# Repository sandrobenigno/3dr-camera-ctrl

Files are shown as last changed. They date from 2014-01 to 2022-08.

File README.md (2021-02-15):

3dr-camera-ctrl
===============

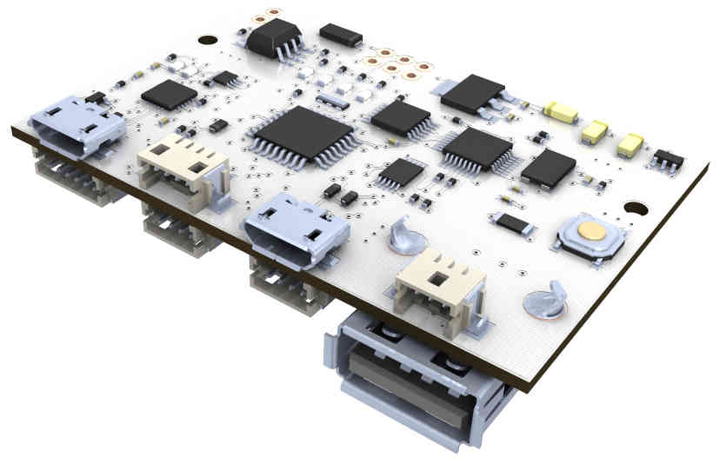
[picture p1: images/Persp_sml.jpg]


3DR Camera Control Board with USB Host

ArduCam PTP CHDK - Arduino based Remote CHDK Camera Control.
This firmware is part of the ArduCAM OSD Project: an open source Arduino based OSD and Camera Control.

<pre>
Author(s): Sandro Benigno
           Legacy PTP commands from Canon's PS-ReCSDK 1.1.0e
           Custom extended PTP commands from CHDK's PTP implementation
           USB host and PTP library from Oleg Mazurov - circuitsathome.com

Note: The PTP library used here was modified by the author.
      There are special characteristics needed to cover the scripting approach.
      The CHDK PTP Transaction has a wider RX buffer (reflected on the dataSize flag).
</pre>

This program is free software; you can redistribute it and/or
modify it under the terms of the GNU General Public License
as published by the Free Software Foundation; either version 2+
of the License, or (at your option) any later version.

This program is distributed in the hope that it will be useful,
but WITHOUT ANY WARRANTY; without even the implied warranty of
MERCHANTABILITY or FITNESS FOR A PARTICULAR PURPOSE.  See the
GNU General Public License for more details.

You should have received a copy of the GNU General Public License
along with this program. If not, see <http://www.gnu.org/licenses/>.

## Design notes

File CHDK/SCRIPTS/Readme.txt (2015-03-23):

GeoShooting base-code for Camera Control over CHDK PTP
This code is part of ArduCAMPTP_CHDK's implementetion for 3DRobotics.

This program is free software; you can redistribute it and/or
modify it under the terms of the GNU General Public License
as published by the Free Software Foundation; either version 2+
of the License, or (at your option) any later version.

This program is distributed in the hope that it will be useful,
but WITHOUT ANY WARRANTY; without even the implied warranty of
MERCHANTABILITY or FITNESS FOR A PARTICULAR PURPOSE.  See the
GNU General Public License for more details.

You should have received a copy of the GNU General Public License
along with this program. If not, see <http://www.gnu.org/licenses/>.

Project page: https://github.com/sandrobenigno/3dr-camera-ctrl

This script receives arguments in a packet of PTP Transaction:

lat   = params[1] <- Latitude.     (E.g. 47.266273)
lon   = params[2] <- Longitude.    (E.g. 11.302096)
alt   = params[3] <- Altitude ASL. (E.g. 1083.22)
pitch = params[4] <- Pitch         (-180 to 180)
row   = params[5] <- Roll          (-180 to 180)
yaw   = params[6] <- Heading       (0.00 <= X < 360.00)

It takes a picture and create/update a file "geostore.csv" on the folder session the taken picture.

Each line of this file looks like this:
IMG_0673.JPG,47.266273,11.302096,1083.22,7,-35,210.00

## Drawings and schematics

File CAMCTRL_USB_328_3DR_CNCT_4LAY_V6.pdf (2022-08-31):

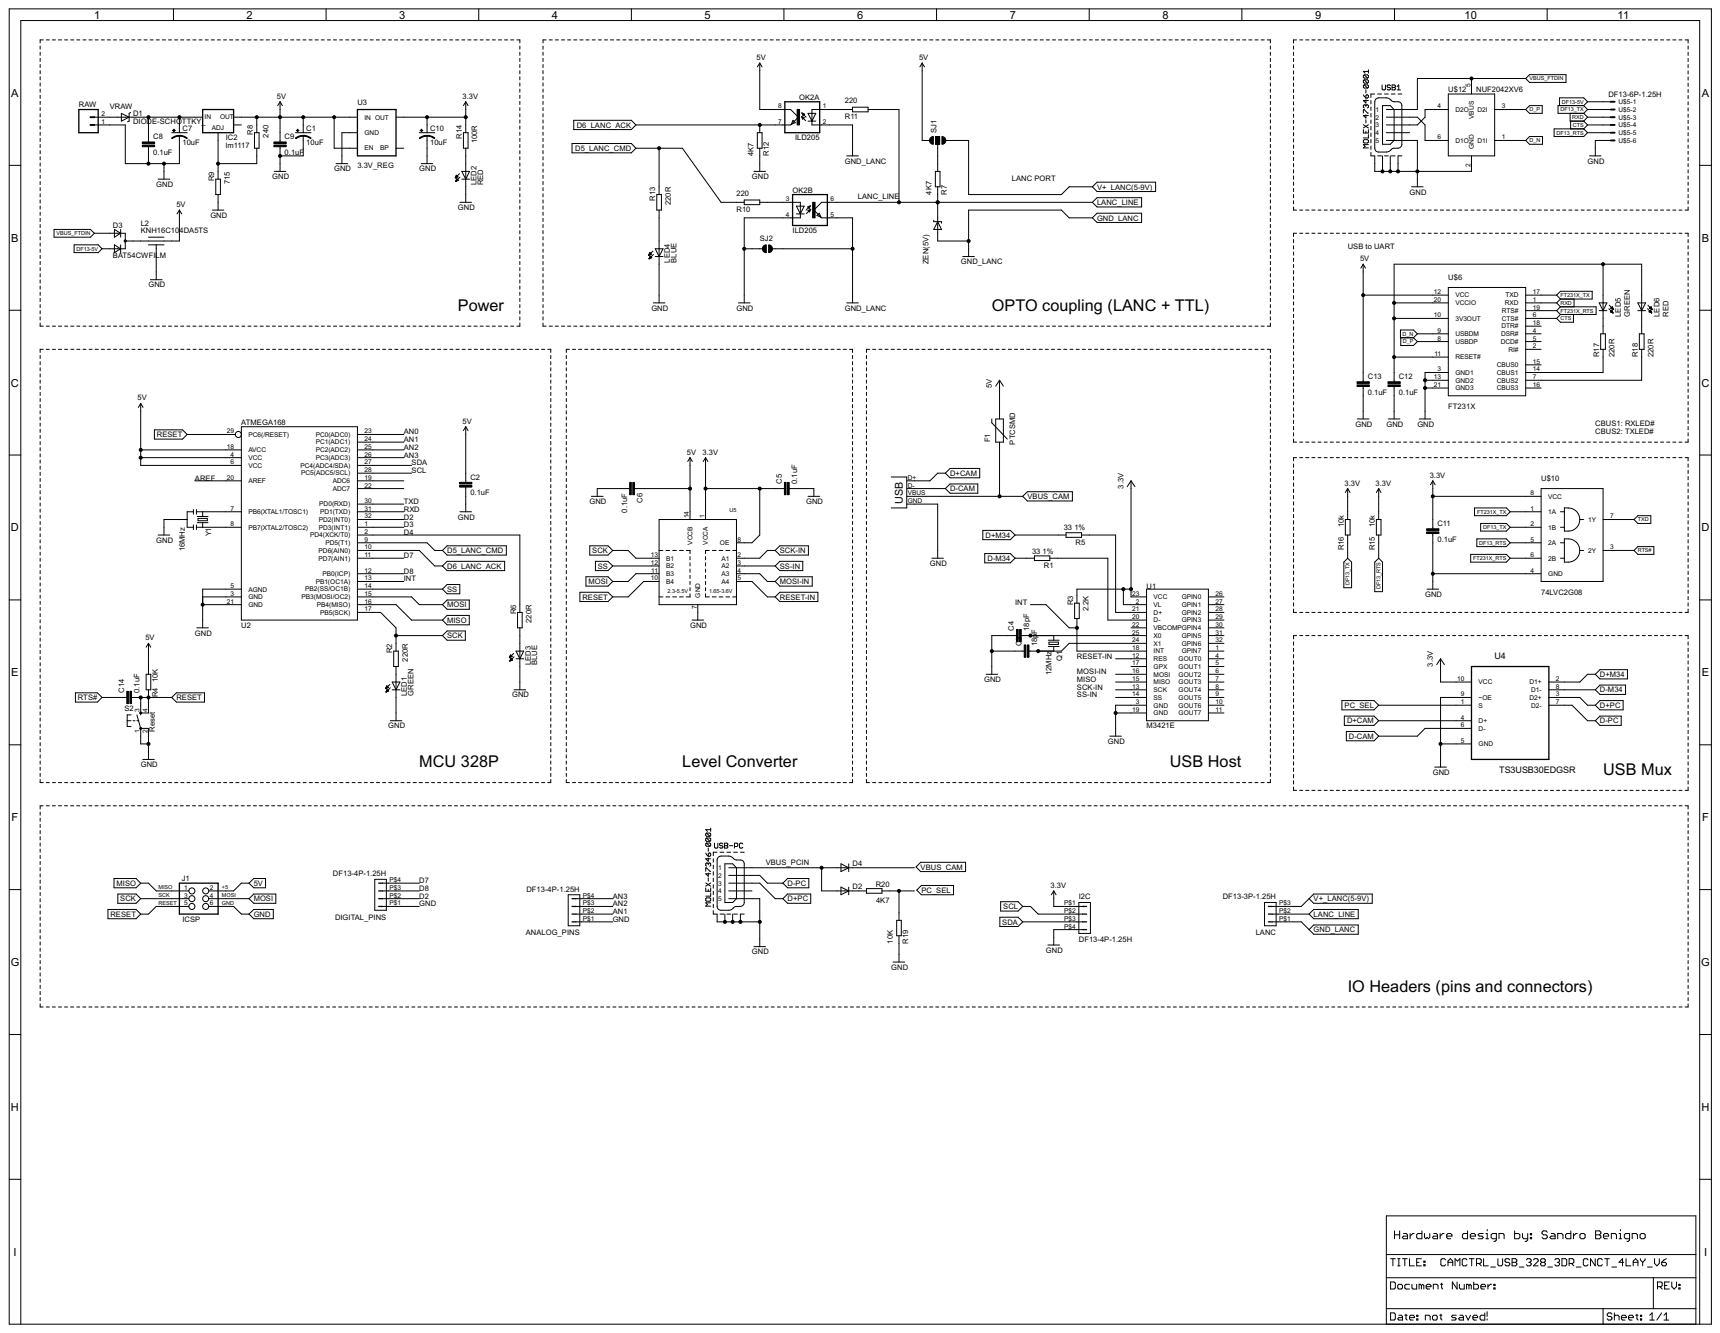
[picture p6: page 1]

LANC PORT OPTO coupling (LANC + TTL)

IO Headers (pins and connectors)

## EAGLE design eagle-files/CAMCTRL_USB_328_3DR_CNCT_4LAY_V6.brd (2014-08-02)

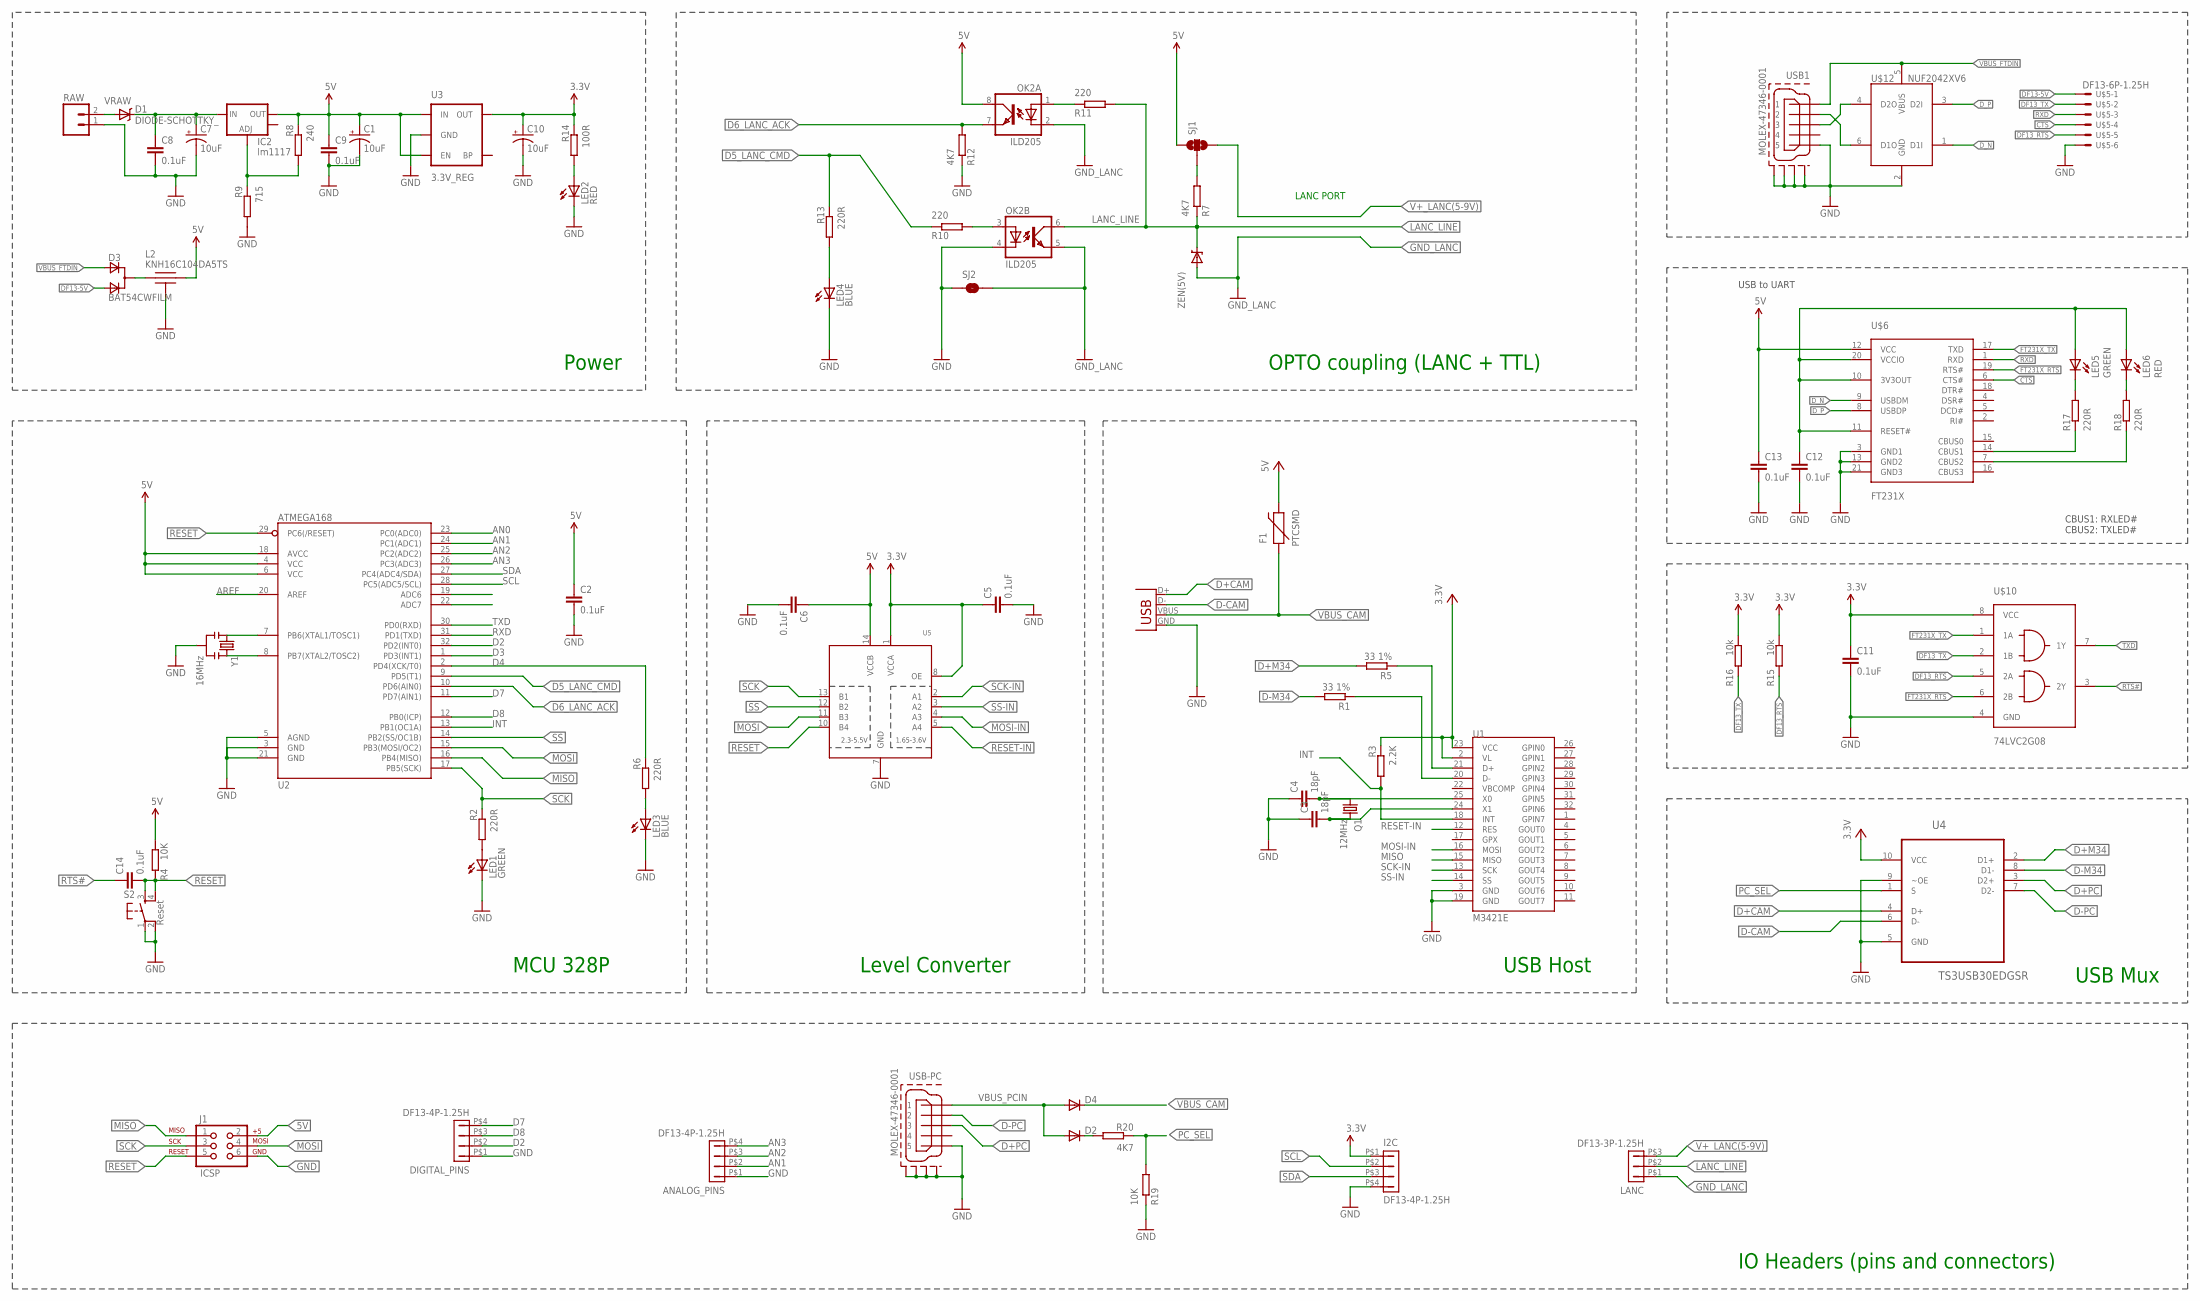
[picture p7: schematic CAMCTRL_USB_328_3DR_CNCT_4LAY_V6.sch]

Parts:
ANALOG_PINS: DF13-4P-1.25H; DF13A-4P-1.25H
C1, C7, C10: 10uF; EIA3216
C2, C5, C6, C8, C9, C11, C12, C13, C14: 0.1uF; 0402-CAP
C3, C4: 18pF; 0402-CAP
D1: DIODE-SCHOTTKY_; SMA-DIODE
D2, D4: DIODE-0603; 0603-DIO
D3: BAT54CWFILM; SOT323
DIGITAL_PINS: DF13-4P-1.25H; DF13A-4P-1.25H
F1: PTCSMD; PTC-1206
I2C: DF13-4P-1.25H; DF13A-4P-1.25H
IC2: lm1117; SOT223
J1: ICSP; 2X3
L2: KNH16C104DA5TS; KYOCERA-KNH16-DA
LANC: DF13-3P-1.25H; DF13A-3P-1.25H
LED1, LED5: GREEN; 0603-LED
LED2, LED6: RED; 0603-LED
LED3, LED4: BLUE; 0603-LED
OK2: ILD205; SOIC08
Q1: 12MHz; CRYSTAL-SMD-5X3
R1, R5: 33 1%; 0402-RES
R2, R6, R13, R17, R18: 220R; 0402-RES
R3: 2.2K; 0402-RES
R4, R19: 10K; 0402-RES
R7, R12, R20: 4K7; 0402-RES
R8: 240; 0402-RES
R9: 715; 0402-RES
R10, R11: 220; 0402-RES
R14: 100R; 0402-RES
R15, R16: 10k; 0402-RES
RAW: M02PTH; 1X02
S2: Reset; TACTILE_SWITCH_SMD
SJ1: SOLDERJUMPER_2WAYPASTE2&3; SJ_3_PASTE2&3
SJ2: SOLDERJUMPER-OLDNO; SJ_2S-NO
U1: M3421E; TQFP32-5MM
U2: ATMEGA168; TQFP32-08
U3: 3.3V_REG; SOT23-5
U4: TS3USB30EDGSR; SOP50P490X110-10N
U5: TXS0104PWR; TSSOP14
U$5: DF13-6P-1.25H; DF13A-6P-1.25H
U$6: FT231X; QFN20
U$10: 74LVC2G08; VFSOP-8
U$12: NUF2042XV6; SOT563-6
USB1: MOLEX-47346-0001
USB-PC: MOLEX-47346-0001
USB_HOST: USB-A-SMD; USB-A-S-NOSILK-FEMALE
Y1: 16MHz; RESONATOR-SMD
ZEN(5V): (5V); 0603-DIO

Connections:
3.3V: C5.P$1 (1), C10.A (+), C11.P$1 (1), I2C.P$1 (1), R3.P$1 (1), R14.P$1 (1), R15.P$1 (1), R16.P$1 (1), U1.2 (VL), U1.23 (VCC), U3.5 (OUT), U4.10 (VCC), U5.1 (VCCA), U5.8 (OE), U$10.8 (VCC)
5V: C1.A (+), C2.P$1 (1), C6.P$1 (1), C9.P$1 (1), C13.P$1 (1), F1.2, IC2.2 (OUT), J1.2, L2.P$2, OK2.8 (COL), R4.P$2 (2), R8.P$1 (1), SJ1.1, U2.4 (VCC), U2.6 (VCC), U2.18 (AVCC), U3.1 (IN), U3.3 (EN), U5.14 (VCCB), U$6.12 (VCC)
AN0: U2.23 (PC0(ADC0))
AN1: ANALOG_PINS.P$2 (2), U2.24 (PC1(ADC1))
AN2: ANALOG_PINS.P$3 (3), U2.25 (PC2(ADC2))
AN3: ANALOG_PINS.P$4 (4), U2.26 (PC3(ADC3))
AREF: U2.20 (AREF)
CTS: U$5.4, U$6.6 (CTS#)
D2: DIGITAL_PINS.P$2 (2), U2.32 (PD2(INT0))
D3: U2.1 (PD3(INT1))
D4: R6.P$1 (1), U2.2 (PD4(XCK/T0))
D5_LANC_CMD: R10.P$1 (1), R13.P$1 (1), U2.9 (PD5(T1))
D6_LANC_ACK: OK2.7 (EMIT), R12.P$2 (2), U2.10 (PD6(AIN0))
D7: DIGITAL_PINS.P$4 (4), U2.11 (PD7(AIN1))
D8: DIGITAL_PINS.P$3 (3), U2.12 (PB0(ICP))
D+CAM: U4.4 (D+), USB_HOST.D+
D+M34: R5.P$2 (2), U4.2 (D1+)
D+PC: U4.3 (D2+), USB-PC.D+ (3)
D-CAM: U4.6 (D-), USB_HOST.D-
D-M34: R1.P$2 (2), U4.8 (D1-)
D-PC: U4.7 (D2-), USB-PC.D- (2)
DF13-5V: D3.3 (A2), U$5.1
DF13_RTS: R15.P$2 (2), U$5.5, U$10.5 (2A)
DF13_TX: R16.P$2 (2), U$5.2, U$10.2 (1B)
D_N: U$6.9 (USBDM), U$12.1 (D1I)
D_P: U$6.8 (USBDP), U$12.3 (D2I)
FT231X_RTS: U$6.19 (RTS#), U$10.6 (2B)
FT231X_TX: U$6.17 (TXD), U$10.1 (1A)
GND: ANALOG_PINS.P$1 (1), C1.C (-), C2.P$2 (2), C3.P$1 (1), C4.P$1 (1), C5.P$2 (2), C6.P$2 (2), C7.C (-), C8.P$2 (2), C9.P$2 (2), C10.C (-), C11.P$2 (2), C12.P$2 (2), C13.P$2 (2), DIGITAL_PINS.P$1 (1), I2C.P$4 (4), J1.6, L2.P$3, L2.P$4, L2.P$5, LED1.C, LED2.C, LED3.C, LED4.C, OK2.4 (C), R9.P$2 (2), R12.P$1 (1), R19.P$1 (1), RAW.1, S2.1, S2.2, SJ2.1, U1.3 (GND), U1.19 (GND), U2.3 (GND), U2.5 (AGND), U2.21 (GND), U3.2 (GND), U4.5 (GND), U4.9 (~OE), U5.7 (GND), U$5.6, U$6.3 (GND1), U$6.13 (GND2), U$6.21 (GND3), U$10.4 (GND), U$12.2 (GND), USB1.GND (5), USB1.GND1, USB1.GND2, USB1.GND3, USB1.GND4, USB-PC.GND (5), USB-PC.GND1, USB-PC.GND2, USB-PC.GND3, USB-PC.GND4, USB_HOST.GND, Y1.2
GND_LANC: LANC.P$1 (1), OK2.2 (C), OK2.5 (EMIT), SJ2.2, ZEN(5V).A
INT: R3.P$2 (2), U1.18 (INT), U2.13 (PB1(OC1A))
LANC_LINE: LANC.P$2 (2), OK2.6 (COL), R7.P$1 (1), R11.P$2 (2), ZEN(5V).C
MISO: J1.1, U1.15 (MISO), U2.16 (PB4(MISO))
MOSI: J1.4, U2.15 (PB3(MOSI/OC2)), U5.11 (B3)
MOSI-IN: U1.16 (MOSI), U5.4 (A3)
unnamed: OK2.3 (A), R10.P$2 (2)
unnamed: U2.7 (PB6(XTAL1/TOSC1)), Y1.1
unnamed: U2.8 (PB7(XTAL2/TOSC2)), Y1.3
unnamed: LED1.A, R2.P$2 (2)
unnamed: C4.P$2 (2), Q1.1, U1.25 (X0)
unnamed: R5.P$1 (1), U1.21 (D+)
unnamed: R1.P$1 (1), U1.20 (D-)
unnamed: C3.P$2 (2), Q1.3 (2), U1.24 (X1)
unnamed: IC2.1 (ADJ), R8.P$2 (2), R9.P$1 (1)
unnamed: OK2.1 (A), R11.P$1 (1)
unnamed: LED3.A, R6.P$2 (2)
unnamed: R7.P$2 (2), SJ1.2
unnamed: D3.1 (C), L2.P$1
unnamed: LED4.A, R13.P$2 (2)
unnamed: U$12.6 (D1O), USB1.D- (2)
unnamed: U$12.4 (D2O), USB1.D+ (3)
unnamed: C12.P$1 (1), LED5.A, LED6.A, U$6.10 (3V3OUT), U$6.11 (RESET#), U$6.20 (VCCIO)
unnamed: R17.P$1 (1), U$6.14 (CBUS1)
unnamed: R18.P$1 (1), U$6.7 (CBUS2)
unnamed: LED5.C, R17.P$2 (2)
unnamed: LED2.A, R14.P$2 (2)
unnamed: LED6.C, R18.P$2 (2)
unnamed: D1.A, RAW.2
unnamed: D2.C, R20.P$2 (2)
PC_SEL: R19.P$2 (2), R20.P$1 (1), U4.1 (S)
RESET: C14.P$2 (2), J1.5, R4.P$1 (1), S2.3, S2.4, U2.29 (PC6(/RESET)), U5.10 (B4)
RESET-IN: U1.12 (RES), U5.5 (A4)
RTS#: C14.P$1 (1), U$10.3 (2Y)
RXD: U2.31 (PD1(TXD)), U$5.3, U$6.1 (RXD)
SCK: J1.3, R2.P$1 (1), U2.17 (PB5(SCK)), U5.13 (B1)
SCK-IN: U1.13 (SCK), U5.2 (A1)
SCL: I2C.P$2 (2), U2.28 (PC5(ADC5/SCL))
SDA: I2C.P$3 (3), U2.27 (PC4(ADC4/SDA))
SS: U2.14 (PB2(SS/OC1B)), U5.12 (B2)
SS-IN: U1.14 (SS), U5.3 (A2)
TXD: U2.30 (PD0(RXD)), U$10.7 (1Y)
V+_LANC(5-9V): LANC.P$3 (3), SJ1.3
VBUS_CAM: D4.C, F1.1, USB_HOST.VBUS
VBUS_FTDIN: D3.2 (A1), U$12.5 (VBUS), USB1.VBUS (1)
VBUS_PCIN: D2.A, D4.A, USB-PC.VBUS (1)
VRAW: C7.A (+), C8.P$1 (1), D1.C, IC2.3 (IN)

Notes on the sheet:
LANC PORT
OPTO coupling (LANC + TTL)
USB Host
Power
MCU 328P
Level Converter
IO Headers (pins and connectors)
USB to UART
CBUS1: RXLED# CBUS2: TXLED#
USB Mux

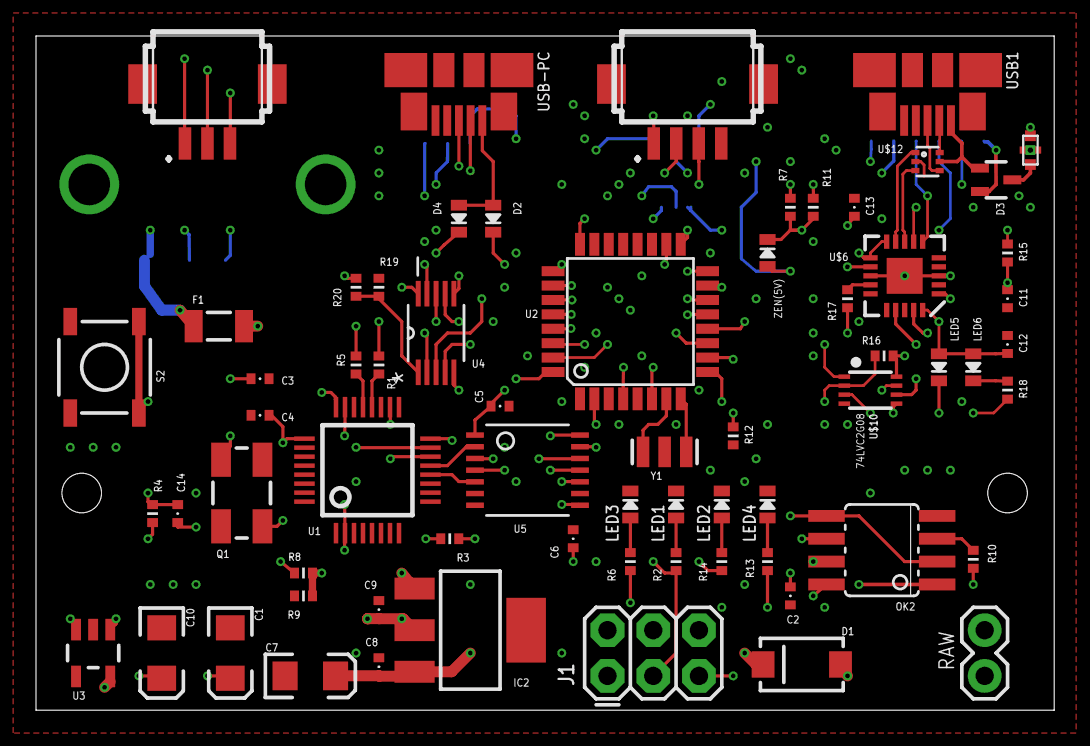
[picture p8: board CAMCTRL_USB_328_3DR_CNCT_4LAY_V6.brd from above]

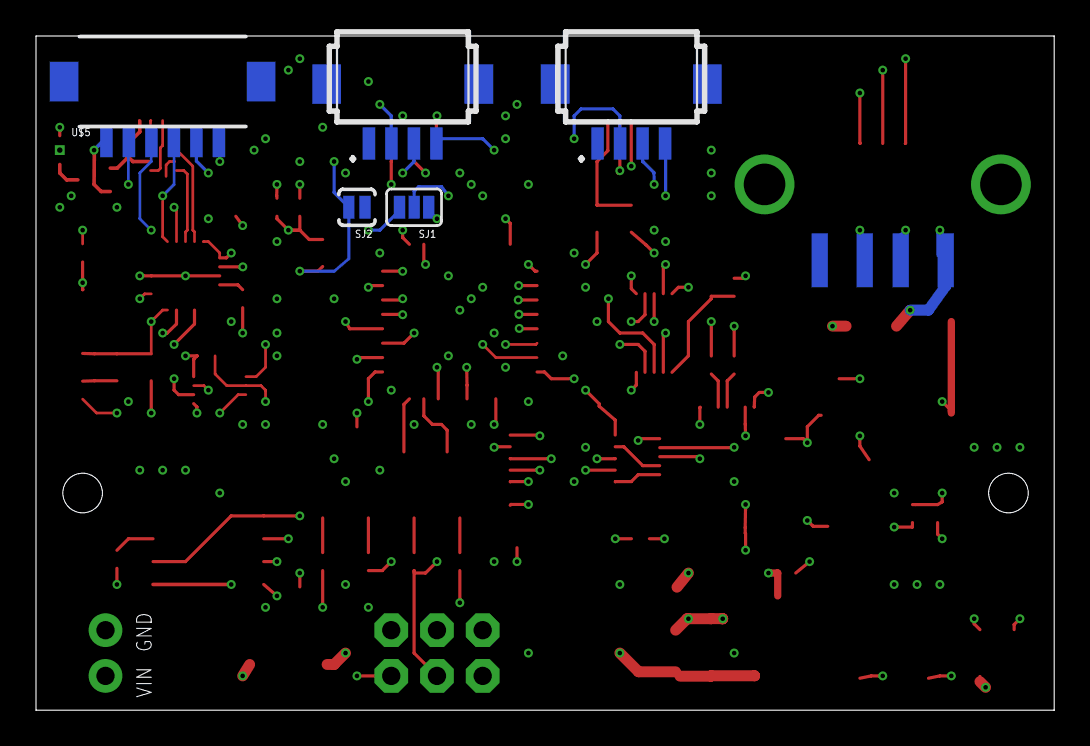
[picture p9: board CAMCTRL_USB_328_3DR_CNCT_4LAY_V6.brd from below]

Board: 4 copper layers, 56.6 x 37.5 mm, 72 parts (6 on the bottom side), 73 nets.

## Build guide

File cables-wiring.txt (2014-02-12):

*************************
*** Cables and Wiring ***
*************************

== Default ==

*Interconnection

   Control Board Usb Host <--cable--> Camera: USB A male to USB Mini male
              PC USB Host <--cable--> Control Board: USB A male to USB Micro male (board programing/camera as external memory)
          Auto Pilot UART <--cable--> Control Board: DF13 6pin male to DF13 6pin male (crossing RX/TX?)

*Broken Out Pins

   Dedicated Lipo Battery ----><pins> right angle 2 pins 0.1" spaced male pin header
 
== Optional ==

*Interconnection

  Control Board LANC <--cable--> Handycam LANC: DF13 3pin to Sony Lanc (D shape or newest one deppending on the model)
  Control Board OPTO(from LANC pins) to SLR Remote: DF13 3pin to 3 pole P2 plug (usually 2.5mm P2 plug)
      Auto Pilot i2c <--cable--> Control Board i2c: DF13 4pin male to DF13 4pin male

*Broken Out Pins

  Control Board's extra ditital pins <--cable--> External Devices: DF13 4pin male to DF13 4pin male
   Control Board's extra analog pins <--cable--> External Devices: DF13 4pin male to DF13 4pin male

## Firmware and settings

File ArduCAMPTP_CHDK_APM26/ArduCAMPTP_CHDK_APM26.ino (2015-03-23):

/*
ArduCam PTP CHDK - Arduino based Remote CHDK Camera Control.
Copyright (c) 2011.  All rights reserved.
This firmware is part of the ArduCAM OSD Project: an open source Arduino based OSD and Camera Control.

Code : ArduCamPTP_CHDK for APM 2.6
Version : v0.97, May 8th 2014

Author(s): Sandro Benigno
                  Legacy PTP commands from Canon's PS-ReCSDK 1.1.0e
                  Custom extended PTP commands from CHDK's PTP implementation
                  USB host and PTP library from Oleg Mazurov - circuitsathome.com

Note: The PTP library used here was modified by the author.
      There are special characteristics needed to cover the scripting approach.
      The CHDK PTP Transaction has a wider RX buffer (reflected as well on the dataSize flag).

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
You should have received a copy of the GNU General Public License
along with this program. If not, see <http://www.gnu.org/licenses/>.
*/

#include <FastSerial.h>

#undef PROGMEM 
#define PROGMEM __attribute__(( section(".progmem.data") )) 

#undef PSTR 
#define PSTR(s) (__extension__({static prog_char __c[] PROGMEM = (s); &__c[0];})) 

#include <avr/interrupt.h> 
//USB lib
#include <usbhub.h>
//PTP lib
#include <ptp.h>
#include "__defines.h"

boolean usbPlugged = false;

FastSerialPort0(Serial);
#ifdef MEGABOARD
FastSerialPort1(Serial1);
FastSerialPort2(Serial2);
FastSerialPort3(Serial3);
#endif

//MAVLINK and companions
#include "AP_Math_AVR_Compat.h"
#include "../mavlink/include/mavlink.h"
#include "cam_ctrl_state.h"
CamCtrlState cam_ctrl_state;
#include "Attitude_defs.h"
#include "MAVcomm.h"

//PTP + CHDK implem dependences
#include <simpletimer.h>
#include "pseventparser.h"
#include "ptp_parser.h"

//PTP CHDK: extended CanonPS class
#include "arducam_chdk_ptp.h"

class CamStateHandlers : public PSStateHandlersCHDK //New CHDK Parser
{
      enum CamStates { stInitial, stDisconnected, stConnected };
      CamStates stateConnected;
    
public:
      CamStateHandlers() : stateConnected(stInitial) {};
      
      virtual void OnDeviceDisconnectedState(PTP *ptp);
      virtual void OnDeviceInitializedState(PTP *ptp);
      virtual void OnDeviceBusyState(PTP *ptp);
} CamStates;

USB         Usb;
//USBHub      Hub1(&Usb);
ArduCAM_PTP Ps(&Usb, &CamStates, AUTOSTART); //New CHDK PTP

SimpleTimer  mavlinkTimer;
SimpleTimer  captureTimer;

double lastShot = 0;
int16_t minShotInt = 1500;
uint8_t xcount = 0;

void CamStateHandlers::OnDeviceDisconnectedState(PTP *ptp)
{
    if (stateConnected == stConnected || stateConnected == stInitial)
    {
        stateConnected = stDisconnected;
        usbPlugged = false;
        captureTimer.Disable();
        
        E_Notify(PSTR("Camera disconnected\r\n"),0x80);
    }
}

void CamStateHandlers::OnDeviceInitializedState(PTP *ptp)
{
    if (stateConnected == stDisconnected || stateConnected == stInitial)
    {
        stateConnected = stConnected;
        usbPlugged = true;
        E_Notify(PSTR("Camera connected\r\n"),0x80);
        captureTimer.Enable();
    }
}

void CamStateHandlers::OnDeviceBusyState(PTP *ptp)
{
    //E_Notify(PSTR("I'm Busy!\r\n"),0x80); 
}

void setup() 
{
  
  pinMode(6,  OUTPUT); //LED Blue (Status) //Old Board
  digitalWrite(6, HIGH); //unplug OSD CHIP //Old Board
  
  //Initialize PINS
  pinMode(4,  OUTPUT); //LED Blue (Status)
  pinMode(10,  OUTPUT); //USB OUT
  pinMode(7,  OUTPUT); //RESET
  pinMode(8,  INPUT); //APM Trigg
  digitalWrite(10, LOW); //plug USB CHIP
  digitalWrite(7, HIGH); //set max reset as it were tied to reset's pull up

  Serial.begin(TELEMETRY_SPEED);
#ifdef MEGABOARD
  Serial1.begin(TELEMETRY_SPEED);
#endif
  Serial.printf_P(PSTR("Start...\n\r"));

  if (Usb.Init() == -1)
            Serial.println("OSC did not start.");

  captureTimer.Set(&OnCaptureTimer, 200);
  mavlinkTimer.Set(&OnMavlinkTimer, 2000);
  mavlinkTimer.Enable();
  delay( 200 );

#ifdef ISR_PIN_D3
/**** My Old prototype: Trigger Pin D3 (PORTD3 INT0) ****/
  EICRA |= (1<<ISC10)|(1<<ISC11);
  EIMSK |= (1<<INT1);
  sei();//Global Int Enabled
#endif

#ifdef ISR_PIN_D8
/**** The New prototype CCB: Trigger Pin D8 (PORTB0 PCINT0)  ****/
  PCMSK0 |= (1<<PCINT0);//Chosen Pin Set by Mask 
  PCICR  |= (1<<PCIE0);//Int source Set
  sei();//Global Int Enabled
#endif
}

void loop() 
{
  //while(!usbPlugged) Usb.Task();
  Usb.Task();
  comm_receive();
  mavlinkTimer.Run();
  captureTimer.Run();
}

void OnCaptureTimer()
{
#ifdef MEGABOARD
  readSerialCommand(); //Commands sent by USB Serial on MegaBoards for testing
#endif
   //Serial.printf_P(PSTR("On capture timer...\n\r"));
  if(cam_ctrl_state.session == 2){ //Check for running session state
    char cm_buffer[20];
    cm_buffer[0] = '\0';
    if(cam_ctrl_state.shot > 0 && (millis() - lastShot) > minShotInt){ //check for FC's "virtual servo" channel for shooting
       cam_ctrl_state.shot = 0;
       geoPic();
     }
     else if(cam_ctrl_state.zoom_pos > 0){ // check for FC's "RC input" channel for shooting
       sprintf(cm_buffer,"set_zoom(%i);", cam_ctrl_state.zoom_pos);
       Ps.ExecScriptCHDK((char*)cm_buffer);
       delay(2000);
       cam_ctrl_state.zoom_pos = -1;
     }
     else if(cam_ctrl_state.focus_lock >= 0){ // check for FC's "RC input" channel for focus ctrl
       sprintf(cm_buffer,"set_aflock(%i);", cam_ctrl_state.focus_lock);
       Ps.ExecScriptCHDK((char*)cm_buffer);
       delay(1500);
       cam_ctrl_state.focus_lock = -1;
     }
  }
  else if(cam_ctrl_state.session >= 0){ //Check for start session command
   //Serial.printf_P(PSTR("On session step...\n\r"));
    if(cam_ctrl_state.session == 1){ //Need do start
      Ps.InitCHDK(true);
      cam_ctrl_state.session = 2; //Now it's running...
    }
    else{// Need to close
      Ps.InitCHDK(false);
      cam_ctrl_state.session = -1; //Now it's closed...  
    }
    delay(2000);
  }
}

#ifdef MEGABOARD
void readSerialCommand() {
  uint16_t res;
  char queryType;
  char buffer[256] = "";
  buffer[0] = '\0';

  if (Serial.available()) {
    queryType = Serial.read();
    switch (queryType) {

    case 'A': //Activate Capture
      res = Ps.InitCHDK(true);
      Serial.printf("Result: 0x%04x\n\r",res);
      delay(3000);
      break;

    case 'C': //Capture!!!
      res = Ps.ExecScriptCHDK("shoot();");
      Serial.printf("Result: 0x%04x\n\r",res);
      delay(2000);
      break;

    case 'D': //Deactivate Capture
      res = Ps.InitCHDK(false);
      Serial.printf("Result: 0x%04x\n\r",res);
      delay(2000);
      break;

    case 'Z': //Set Zoom 0 - 10 (Example: Z5 or Z10)
      strcat(buffer, "set_zoom(");
      strcat(buffer, readCommandSerial());
      strcat(buffer, ");");
      res = Ps.ExecScriptCHDK((char*)buffer);
      Serial.printf("Result: 0x%04x\n\r",res);
      delay(1000);
      break;

    case '#': //Custom Commands
      strcat(buffer, readCommandSerial());
      res = Ps.ExecScriptCHDK((char*)buffer);
      Serial.printf("Result: 0x%04x\n\r",res);
      delay(2000);
      break;
    }
  }
}

char* readCommandSerial() {
  byte index = 0;
  byte timeout = 0;
  char data[256] = "";

  do {
    if (Serial.available() == 0) {
      delay(10);
      timeout++;
    }
    else {
      data[index] = Serial.read();
      timeout = 0;
      index++;
    }
  }  
  while ((data[constrain(index-1, 0, 256)] != ';') && (timeout < 10) && (index < 256));
  return data;
}
#endif

void OnMavlinkTimer()
{
  
  //Serial.println("On mavlink timer...");
#ifdef MAVREPORT
  Serial.printf("Pitch: %4.0i Roll: %4.0i Heading: %4.2f\n\r", drone_pitch, drone_roll, drone_heading);
  Serial.printf("Lat: %11.6f Lon: %11.6f Alt: %5.2f\n\r", drone_lat, drone_lon, drone_alt_asl);
  Serial.printf("RC5: %4.0i, RC6: %4.0i, RC7: %4.0i, RC8: %4.0i\n\r", drone_chan[0], drone_chan[1], drone_chan[2], drone_chan[3]);
  Serial.printf("CH7: %4.0i, CH8: %4.0i\n\r", drone_servo[0], drone_servo[1]);
#endif

#ifdef TESTPIC
  if(xcount > 2){
    xcount = 0;
    PORTD |= (1 << PORTD4);
    takePic = true;
    Serial.printf_P(PSTR("Pic...\n\r"));
  }
  xcount++;
#endif
}

void geoPic()
{
  //buffers
  char g_buffer[128] = "";
  g_buffer[0] = '\0';
  char c_lat[11];
  char c_lon[11];
  char c_alt[9];
  char c_heading[8];

  //Format
  const char* g_form = "loadfile('A/CHDK/SCRIPTS/geoshot.lua')('%s','%s','%s','%i','%i','%s');";
  
  //Converting Floats
  dtostrf(drone_lat,1,6,c_lat);
  dtostrf(drone_lon,1,6,c_lon);
  dtostrf(drone_alt_asl,1,2,c_alt);
  dtostrf(drone_heading,1,2,c_heading);
  
  sprintf(g_buffer,g_form, c_lat, c_lon, c_alt, drone_pitch, drone_roll, c_heading);
  Ps.ExecScriptCHDK((char*)g_buffer);
  //#loadfile('A/CHDK/SCRIPTS/geoshot.lua')('47.266273','11.302096','1083.22','7','-35','210.00');
  //Ps.ExecScriptCHDK("shoot();");
  digitalWrite(4,  LOW); //LED OFF
  lastShot = millis();
}

#ifdef ISR_PIN_D3
/**** My Old prototype: Trigger Pin D3 (PORTD3 INT0) ****/
ISR (INT1_vect) {
  PORTD |= (1 << PORTD4);
  takePic = true;
}
#endif

#ifdef ISR_PIN_D8
/**** The New prototype CCB: Trigger Pin D8 (PORTB0 PCINT0) ****/
ISR (PCINT0_vect) { 
  if(PORTB & (1 << PORTB0) == (1 << PORTB0)){
    PORTD |= (1 << PORTD4);
    takePic = true;
  }
}
#endif

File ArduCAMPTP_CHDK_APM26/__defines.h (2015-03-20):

#ifndef __DEFINES__
#define __DEFINES__

/*
ArduCam PTP CHDK - Arduino based Remote CHDK Camera Control.
Copyright (c) 2011.  All rights reserved.
This firmware is part of the ArduCAM OSD Project: an open source Arduino based OSD and Camera Control.

Author(s): Sandro Benigno
                  Legacy PTP commands from Canon's PS-ReCSDK 1.1.0e
                  Custom extended PTP commands from CHDK's PTP implementation
                  USB host and PTP library from Oleg Mazurov - circuitsathome.com
                  
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
You should have received a copy of the GNU General Public License
along with this program. If not, see <http://www.gnu.org/licenses/>.
*/

//uncoment if using Mega or ADK boards
//#define MEGABOARD 1

#define AUTOSTART 0 //Expose lens on start (Startr on Record Mode)
#define TELEMETRY_SPEED 57600
#define MAX_ZOOM_STEPS 10

#ifdef MEGABOARD
  //1280 or 2560 Boards
  #define MAVLINK_COMM_NUM_BUFFERS 2
  #define MAVLINK_CHANNEL MAVLINK_COMM_1
  #define Serialx Serial1
#else
  //328P Boards
  #define MAVLINK_COMM_NUM_BUFFERS 1
  #define MAVLINK_CHANNEL MAVLINK_COMM_0
  #define Serialx Serial
#endif

//Define mapping of FC IN channel to coltroll each function
//Pay attention to the RC IN chosen as Flight Control Mode
#define DRONE_LENSES 0 //RC IN from 5 to 8 (0,1,2,3)(OFF/ON)
#define DRONE_FLOCK 2 //RC IN from 5 to 8 (0,1,2,3)(OFF/ON)
#define DRONE_ZOOM 3 //RC IN from 5 to 8 (0,1,2,3)(Range from 1000 to 2000 as 0 to 100%)

//Define what FC OUT channel is the trigger
//#define DRONE_OUT 0 //Shutter RC7
#define DRONE_OUT 1 //Shutter RC8

//*Uncomento to Enable PTP Scripts being executed
//#define PTPREPORT 1

//Uncomment to Enable Test pics
//#define TESTPIC 1

//*Uncomment to see Attitude plus the monitored drone's IN/OUT Data
//*Do ***NOT*** enable that on 328p boards ("Capture Timer" have to be disabled for testing it on 328p)
//#define MAVREPORT 1

//Uncomment to Enable ISR Triggering on Pin D3 (PORTD3 INT0)
//#define ISR_PIN_D3

//Uncomment to Enable ISR Triggering on Pin D8 (PORTB0 PCINT0
//#define ISR_PIN_D8

#endif //!defined DEFINES

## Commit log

2014-01-24 Eagle CAD files
    Camera Control Board design, including schematic and the four- layer
    routing. It's under version 3 (prototyping fase).
    [CAMCTRL_USB_328_3DR_CNCT_4LAY_V3.brd, CAMCTRL_USB_328_3DR_CNCT_4LAY_V3.sch]
2014-01-24 Cables and Wiring
    Description of cables and pin-headers. It's needed for interconnection
    and for having access to the broken out pins.
2014-01-24 Preliminar Code for Camera Control under CHDK PTP
    Code base for PTP camera control over USB Host.
    Note: This code is based on a test-bed hardware. It needs to be adapted
    to the final prototype. one
2014-02-12 Updated Code and Board
    Updated test code with new object info handling, zooming command and
    some extra clean-ups.
    Board updated with replaced LED's resistors.
    [CAMCTRL_USB_328_3DR_CNCT_4LAY_V4.brd, CAMCTRL_USB_328_3DR_CNCT_4LAY_V4.sch]
2014-02-12 Correcting a small typo
    Wrong call to ptpobjhandleparser.h
    [ArduCAMPTP_CHDK.ino]
2014-03-21 Prototype V2
    USB interruption line added;
    VCC vs 5V wrong propagation corrected.
    [CAMCTRL_USB_328_3DR_CNCT_4LAY_V4.brd, CAMCTRL_USB_328_3DR_CNCT_4LAY_V4.sch]
2014-03-31 Prototype V2.1
    4k7 resistor added to the USB-Mux's "select" pin.
    [CAMCTRL_USB_328_3DR_CNCT_4LAY_V4.brd, CAMCTRL_USB_328_3DR_CNCT_4LAY_V4.sch]
2014-04-01 Level Converter Replacement
    TXB0104PWR replaced by a TXS0104PWR (larger current draw on the IO). A
    10K OE resistor was added as well.
    [CAMCTRL_USB_328_3DR_CNCT_4LAY_V4.brd, CAMCTRL_USB_328_3DR_CNCT_4LAY_V4.sch]
2014-05-09 APM 2.6 Triggering and MAVLink
    Triggering the board by Relay (Camera Control Inputs D3 or D8).
    Telemetry is grabed from APM 2.6 UART2
2014-05-09 GeoShooting base-code for Camera Control over CHDK PTP
    Script called from a PTP transaction. It does receive telemetry data,
    takes a picture, creating or updating a file with GPS/IMU data. The
    filename is "geostore.csv". It is created in the folder session of taken
    pictures.
2014-06-09 Code for pure MAVLink Operation
    Biggest changes on Libraries and the base-code.
    Default operation uses MAVLink msgs for show lenses, foucus_lock,
    zooming and triggering.
    Default internal APM control:
    Shutter Setup --> RC8 (1000 - 2000)
    APM Input Channels:
    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
2014-08-02 HardWare V6
    10K eliminated from the TXS0104PWR OE pin.
    [CAMCTRL_USB_328_3DR_CNCT_4LAY_V6.brd, CAMCTRL_USB_328_3DR_CNCT_4LAY_V6.sch]
2014-08-02 Hardware V4 removed
    Removed "Hardware V4" from "eagle-files" folder.
    [CAMCTRL_USB_328_3DR_CNCT_4LAY_V4.brd, CAMCTRL_USB_328_3DR_CNCT_4LAY_V4.sch]
2022-08-31 Adding the hw design in PDF
    The schematic of the 3DR Camera Control in PDF.

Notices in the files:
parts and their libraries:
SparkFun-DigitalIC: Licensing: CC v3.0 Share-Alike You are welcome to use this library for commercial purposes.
